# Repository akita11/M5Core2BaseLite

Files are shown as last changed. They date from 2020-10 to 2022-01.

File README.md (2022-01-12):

# M5CoreBaseLite

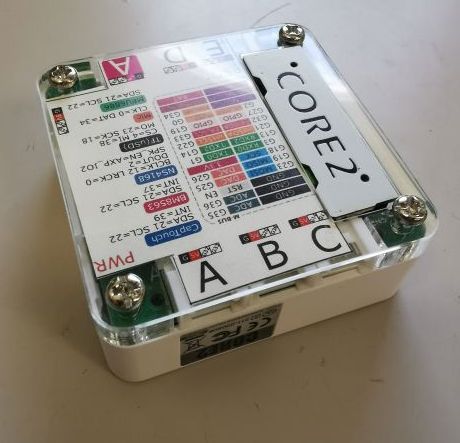
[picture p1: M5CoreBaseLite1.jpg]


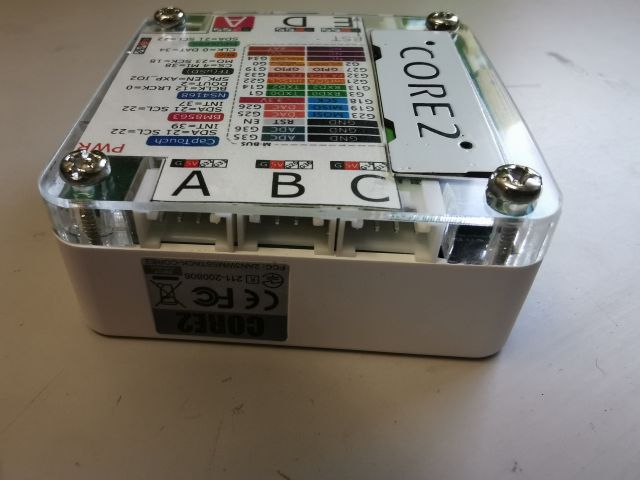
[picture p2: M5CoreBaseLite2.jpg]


- [M5StackCore2](https://www.switch-science.com/catalog/6530/)の底板と交換し、各種UNIT等を接続するPortを増設します。
- PortはA, B, C, D, Eの5種類があり、そのうちPortAは2個（うち1個は電源電圧を3.3Vに変更できます）あります。※v1.0aから、PortAはいずれも電源電圧5Vとなりました（うち1つ(PortA')は3.3Vに変更可能：後述）
- これらのPortは、UIFlowから利用できます。また以下のGPIOの割当を使って、ArduinoIDE等からも利用できます。
- コネクタの色は、この写真ではすべて白ですが、後述のようにPortA/B/C/D/Eで色を分けることもできます。

これを使う[ハンズオン資料(GomiHgy氏作)](https://docs.google.com/presentation/d/11nBajGIhjv-naQnr_dzS9U8Bt7wMfS5UbUuWfKnAS3c/edit#slide=id.p)などで、M5StackCore2を使ったIoT演習などに活用できます。

## 組み立て方 / How to Build 

1. 以下の部品を用意します。

  - ボード
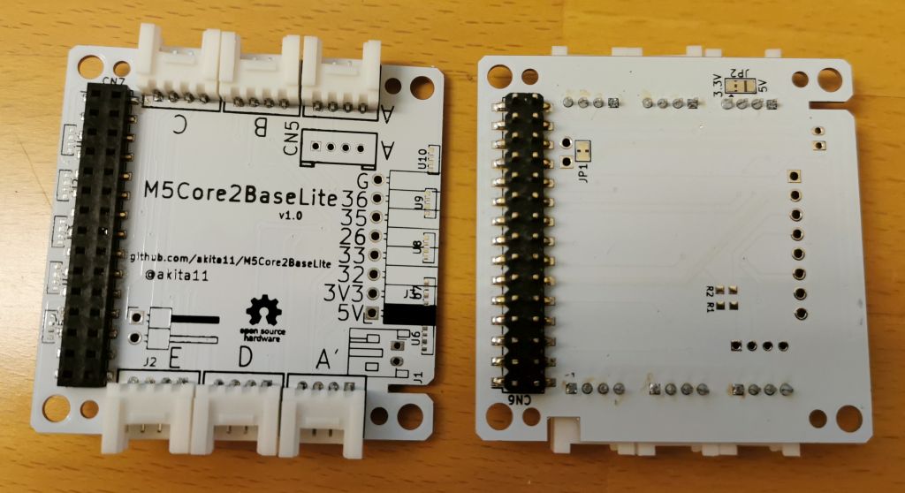
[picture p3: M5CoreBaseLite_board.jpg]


  - アクリル板（3種）※v1.0aから一部部材の形状が変更になっています
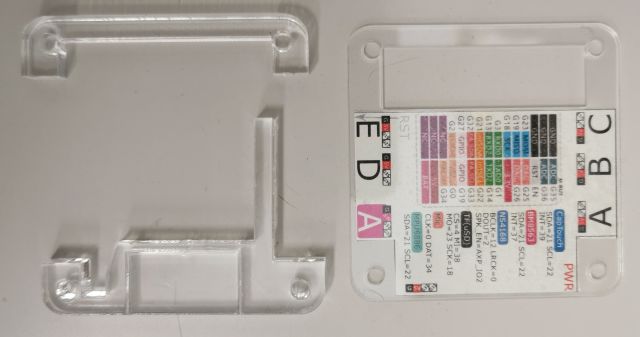
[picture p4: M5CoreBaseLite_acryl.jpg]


  - M3ネジ（20mm x 2本、15mm x 2本）

2. M5StackCore2の底板と、加速度センサが載っている小ボードををはずします。
またリチウムイオンバッテリを底板から外しておきます（本体コネクタからは外さない）。
なおリチウムイオンバッテリに取り付けられている両面テープが、Core2のロットによってはバッテリの逆面についているようで、あとで取り付けるアクリル板(1mm)にくっつくのが気になる場合は、適当な方法でカバーします（この例では養生テープを貼っています）。
（※2mmの六角レンチが必要です。100均やホームセンター等で購入してください）

3. リチウムイオンバッテリをボードの溝を通しつつ、本体M5StackCore2本体にボードをとりつけ、アクリル板（2種）を置きます。

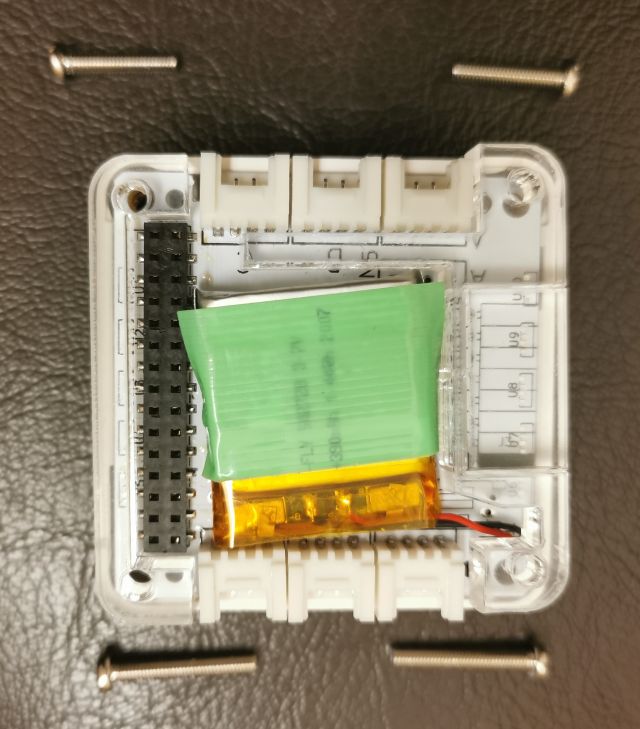
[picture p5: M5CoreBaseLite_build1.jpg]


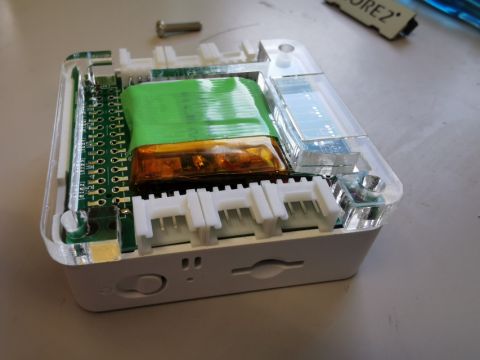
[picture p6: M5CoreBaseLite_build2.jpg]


4. アクリル板（1mm厚）を置き、上の図のネジがおいてある場所の近くの長さのネジで、アクリル板（すべて）、ボード、M5StackCore2を固定します。
（※とりつけるネジの長さに注意）

## サイドの8pコネクタ（オプション）

オプションで8pメスソケットを取り付け、5本のIO(G26, G32, G33, G35, G36)と5V/3.3Vの電源を横に引き出すことができます。
ジャンパワイヤ等で使用できます。
アクリル板の切り込みに沿ってカットします。（細い部分が折れやすいため、折れてしまった場合は、そのままネジで固定するか、透明ボンド等で固定してください）
なお底板ラベルの隅に、このコネクタのピン配置があるので、カットしてコネクタに貼ってください。

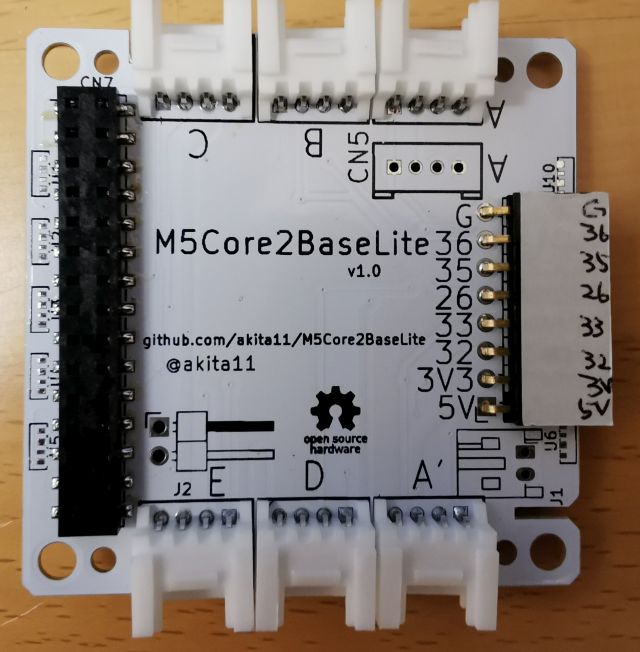
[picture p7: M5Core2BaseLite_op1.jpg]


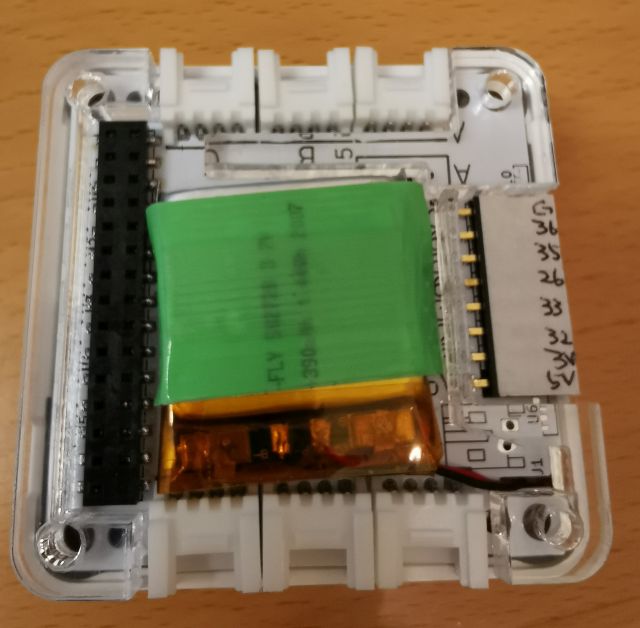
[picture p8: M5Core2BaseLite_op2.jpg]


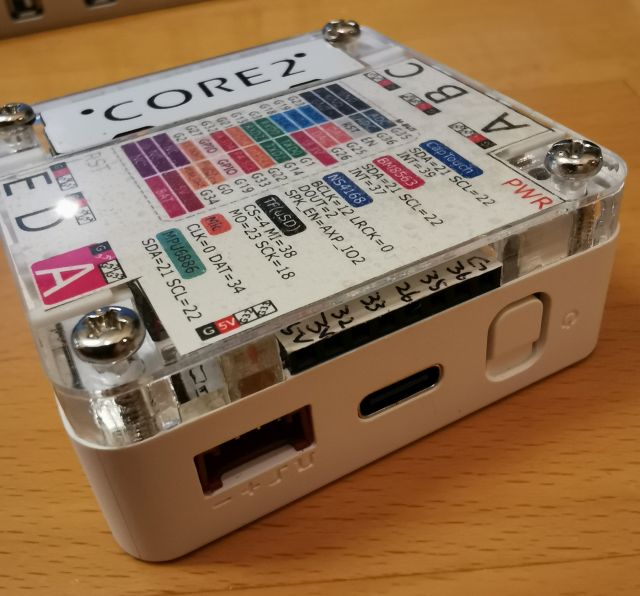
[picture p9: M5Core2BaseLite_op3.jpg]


## 各ポートとGPIOの対応

※底板のラベルにも書いてあります
- PortA,A'(赤): G32/G33
- PortB(黒): G26/G36
- PortC(青): G14/G13
- PortD(緑／黄緑): G35/G34
- PortE(黄): G19/G27

なおPortA'（ピンク色で表示）の電源電圧は、ボード裏面のハンダジャンパの"5V"側をカットし、"3.3V"側にハンダを盛ることで、3.3Vに切り替えることができます。
※初期のv1.0では、初期設定が3.3Vになっています。"3.3V"側をカットし、"5V"側にハンダを盛ることで、5Vに切り替えることができます。

※PortDのG34は、Core2-ext（Core2に付属の、底板につけるマイクと加速度センサの載った小さなボード）のマイクに接続されていますので、Core2-extを接続時にはPortDのG34は使用できません。

# Author

Junichi Akita (@akita11, akita@ifdl.jp)

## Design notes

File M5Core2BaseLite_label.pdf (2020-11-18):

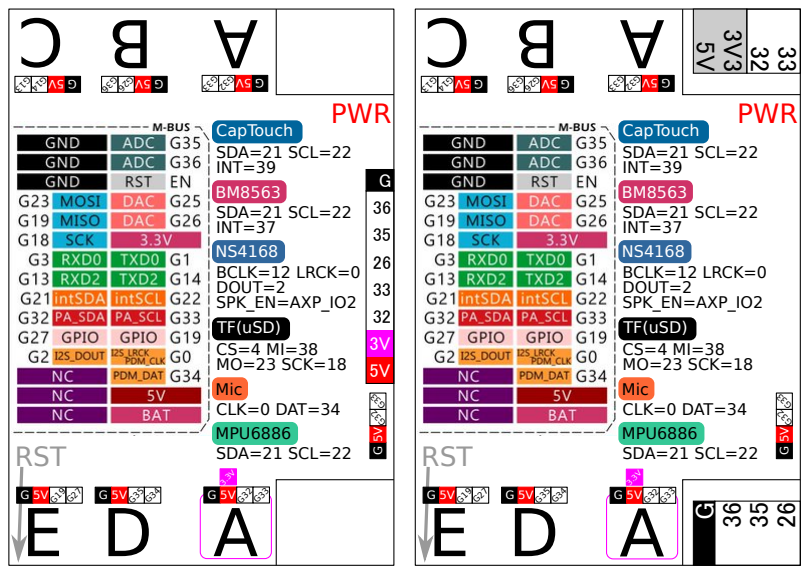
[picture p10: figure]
RST; PWR; CapTouch; TF(uSD); Mic; SDA=21 SCL=22 INT=37; SDA=21 SCL=22 INT=39; CS=4 MI=38 MO=23 SCK=18; BCLK=12 LRCK=0 DOUT=2 SPK_EN=AXP_IO2; CLK=0 DAT=34 MPU6886 SDA=21 SCL=22

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
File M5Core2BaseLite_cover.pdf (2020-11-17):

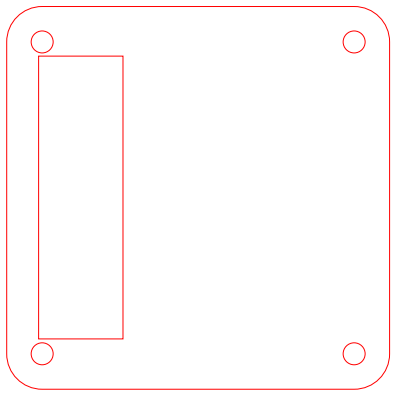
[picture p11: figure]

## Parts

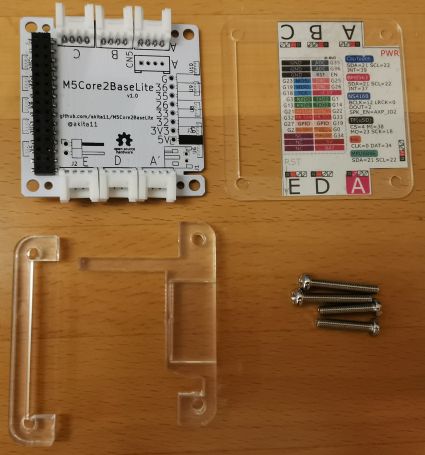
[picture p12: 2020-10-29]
M5Core2BaseLite_parts.jpg

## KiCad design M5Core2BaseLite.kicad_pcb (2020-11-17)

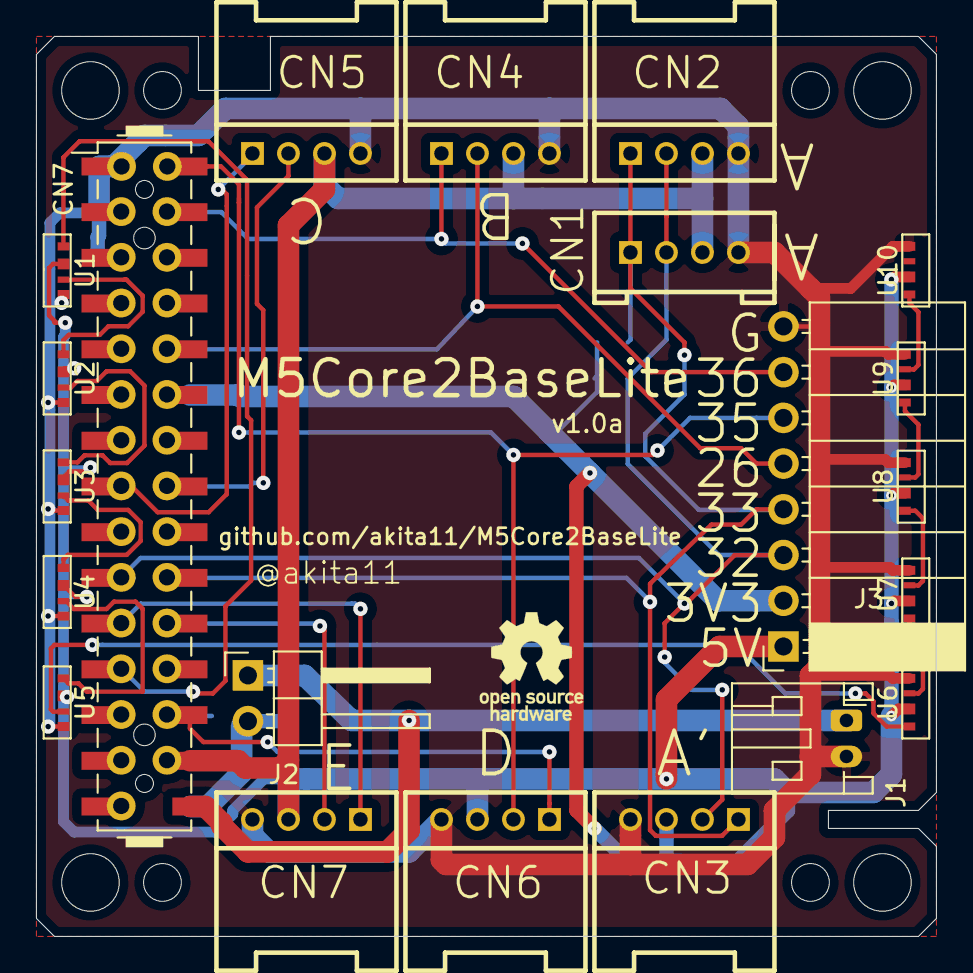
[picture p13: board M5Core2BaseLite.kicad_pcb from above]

Board: 2 copper layers, 50.0 x 50.0 mm, 34 parts (0 on the bottom side), 28 nets.

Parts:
CN1: CON_GROVEV; CON_GROVE_V
CN2, CN3, CN4, CN5, CN6, CN7#2: CON_GROVEH; CON_GROVE_H
CN7: PinHeader_2x15_P2.54mm_Vertical_SMD
CN8: MBUS_bottom; PinSocket_2x15_P2.54mm_Vertical_SMD
J1: Conn_01x02_Female; JST_PH_S2B-PH-K_1x02_P2.00mm_Horizontal
J2: Conn_01x02_Female; PinHeader_1x02_P2.54mm_Horizontal
J3: Conn_01x08_Female; PinSocket_1x08_P2.54mm_Horizontal
JP1: SolderJumper_2_Bridged; SolderJumper-2_P1.3mm_Bridged_Pad1.0x1.5mm
JP2: SolderJumper_3_Bridged12; SolderJumper-3_P1.3mm_Bridged2Bar12_Pad1.0x1.5mm
MH1, MH1#2, MH1#3, MH2: MountingHole_3.2mm_M3
MH5, MH5#2, MH5#3, MH5#4: MountingHole_2.1mm
R1, R2: 4.7k; 0603
U1, U2, U3, U4, U5, U6, U7, U8, U9, U10: LED_SK6812side; LED_SK6812SIDE

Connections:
+3V3: CN7.12, CN8.12, J3.2, JP2.3, R1.2, R2.2
+5V: CN1.3, CN2.3, CN4.3, CN5.3, CN6.3, CN7.28, CN7#2.3, CN8.28, J3.1, JP2.1, U1.2, U2.2, U3.2, U4.2, U5.2, U6.2, U7.2, U8.2, U9.2, U10.2
/BAT: CN8.30, J2.2, JP1.2
/GPIO2: CN1.2, CN2.2, CN3.2, CN7.19, CN8.19, J3.3, R2.1
/GPIO5: CN1.1, CN2.1, CN3.1, CN7.20, CN8.20, J3.4, R1.1
/GPIO12: CN7.21, CN7#2.1, CN8.21
/GPIO13: CN7.22, CN7#2.2, CN8.22
/GPIO15: CN7.23, CN8.23, U1.1
/GPIO26: CN4.2, CN7.10, CN8.10, J3.5
/GPIO34: CN6.1, CN7.26, CN8.26
/GPIO35: CN6.2, CN7.2, CN8.2, J3.6
/GPIO36: CN4.1, CN7.4, CN8.4, J3.7
/RXD: CN5.1, CN7.15, CN8.15
/SCL: CN7.18, CN8.18
/SDA: CN7.17, CN8.17
/TXD: CN5.2, CN7.16, CN8.16
GND: CN1.4, CN2.4, CN3.4, CN4.4, CN5.4, CN6.4, CN7.1, CN7.3, CN7.5, CN7#2.4, CN8.1, CN8.3, CN8.5, J1.2, J3.8, U1.4, U2.4, U3.4, U4.4, U5.4, U6.4, U7.4, U8.4, U9.4, U10.4
unnamed: CN3.3, JP2.2
unnamed: CN7.30, J1.1, J2.1, JP1.1
unnamed: U1.3, U2.1
unnamed: U2.3, U3.1
unnamed: U3.3, U4.1
unnamed: U4.3, U5.1
unnamed: U5.3, U6.1
unnamed: U6.3, U7.1
unnamed: U7.3, U8.1
unnamed: U8.3, U9.1
unnamed: U9.3, U10.1

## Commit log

2020-10-14 add board data
    [M5Core2BaseLite.kicad_pcb, M5Core2BaseLite.sch]
2020-10-22 add silk notice for CN6/7
    [M5Core2BaseLite.kicad_pcb]
2020-10-29 写真を整理、8pコネクタ追記
2020-10-29 ラベルを更新
2020-11-17 v1.0aの情報を追記
2020-11-17 アクリルカバーデータの更新(v1.0a)
2020-11-17 基板データをv1.0a（PortA'をデフォルト5V）に変更
    [M5Core2BaseLite.kicad_pcb, M5Core2BaseLite.sch]
2020-11-17 底板ラベルをv1.0a用に更新
2020-11-17 PortA'の電源電圧設定方法を追記
2020-11-18 底板ラベルの位置を微調整
2021-02-07 readmeにハンズオン資料へのリンクを追加
2022-01-12 Core2-extについての名称の変更
